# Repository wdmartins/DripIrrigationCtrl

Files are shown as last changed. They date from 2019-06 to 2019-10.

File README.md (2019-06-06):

# DripIrrigationCtrl

Smart Control for Drip Irrigation

This project is aimed to control vegetable garden drip irrigation by setting start dripping time, duration, frequency, rain delay, etc. It also reports water flow measurements.

## Features

* MQTT enabled. Setup and control drip irrigation settings by using MQTT commands.

* LCD Display. Display time and system status on a 16x2 Liquid Crystal Display

* Push Button. Restart system, restart Wi-Fi settings, manual start/stop dripping, and set rain delay using a single push button.

* LED indication. Indicates initialization, normal status, and dripping by flashing LED.

* Peristent Setting Storage. Dripping settings are persistently stored in EEPROM

* OTA. Over the air update is enabled by default.

## Operation

* First time operation. Power the system and connect to the AP (esp8266/esp8266) and navigate to the ip address showed in the display. Setup your WiFi SSID and password so the system can connect to your network.

* Upon restart the system initializes by connecting to the Wi-Fi, setup a connection to the MQTT broker and schedule next dripping period (or start dripping) based on default dripping settings.

* Push Button Operation:

  * Short Push (less than 3 seconds) will start/stop dripping
  * Medium push (less than 8 seconds) will set a 24 hours rain delay.
  * Long Push (more than 8 seconds) will restart the system
  * Power up while pushing button will reset Wi-Fi settings and start the system in AP mode.

* MQTT Commands:

  By default the system subscribes to MQTT topic /home-assistant/drip/request. The payload includes the command (first byte), and the data (subsequent bytes)
  * Dripping Settings Payload: cHH:MM:SSMMHH where HH:MM:SS (24 hours format) is start time, MM duration (in minutes), and HH period (in hours)
  * Rain Delay Payload: rHH where HH is the rain delay in hours
  * Start Dripping Payload: sMM where MM is the dripping time in minutes
  * Stop Dripping Paylod:  t
  * Reset Payload: x
  
  The system will also report using the following MQTT command:

  * /home-assistant/drip/flow the payload will have the metered water flow after each dripping cycle. Payload: xxx where xxx is the total liters.
  * /home-assistant/drip/started drip has started. No payload.
  * /home-assistant/drip/stopped drip has stopped. No payload.

## Schemmatic
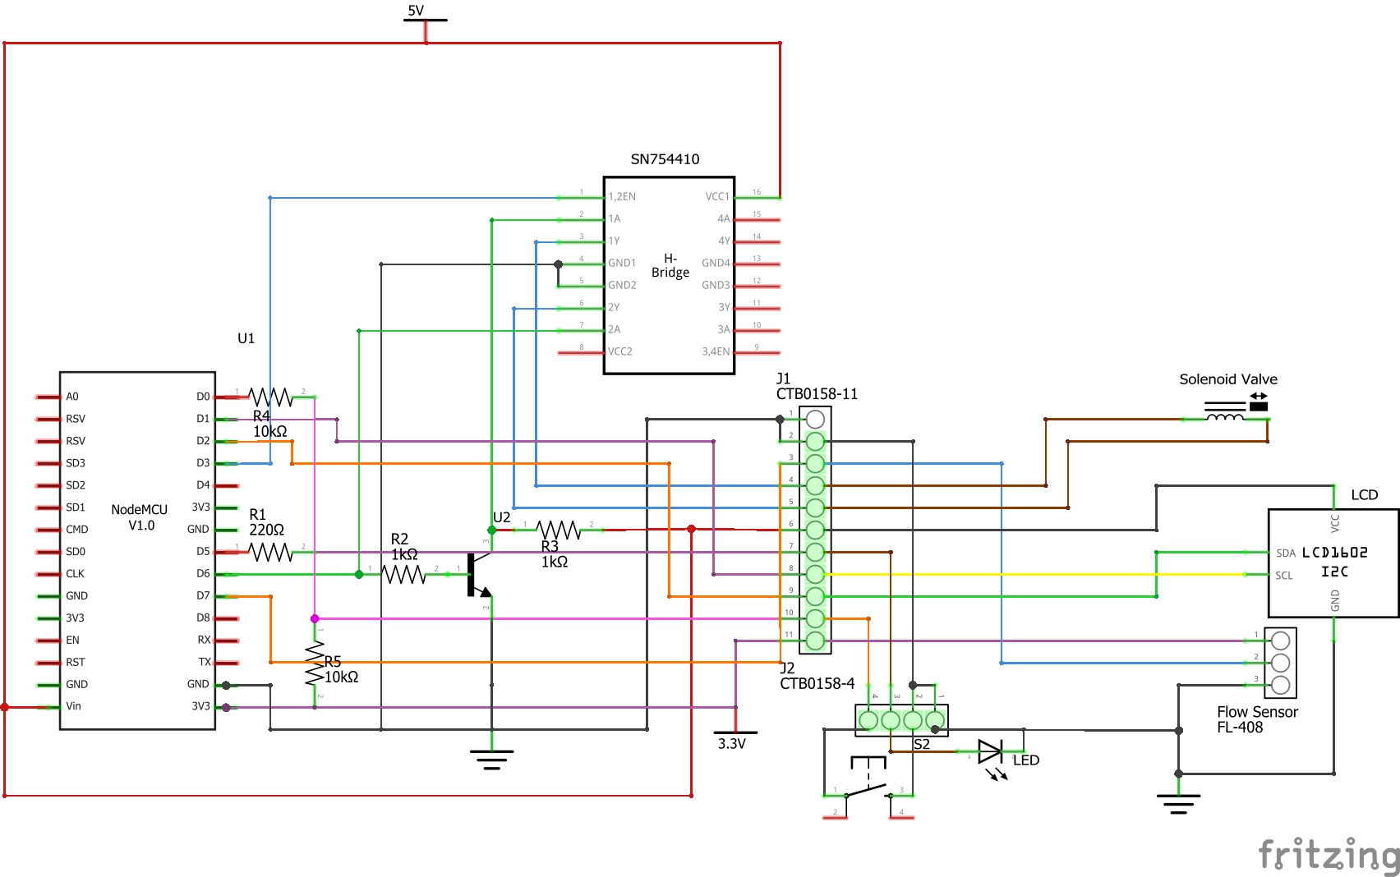
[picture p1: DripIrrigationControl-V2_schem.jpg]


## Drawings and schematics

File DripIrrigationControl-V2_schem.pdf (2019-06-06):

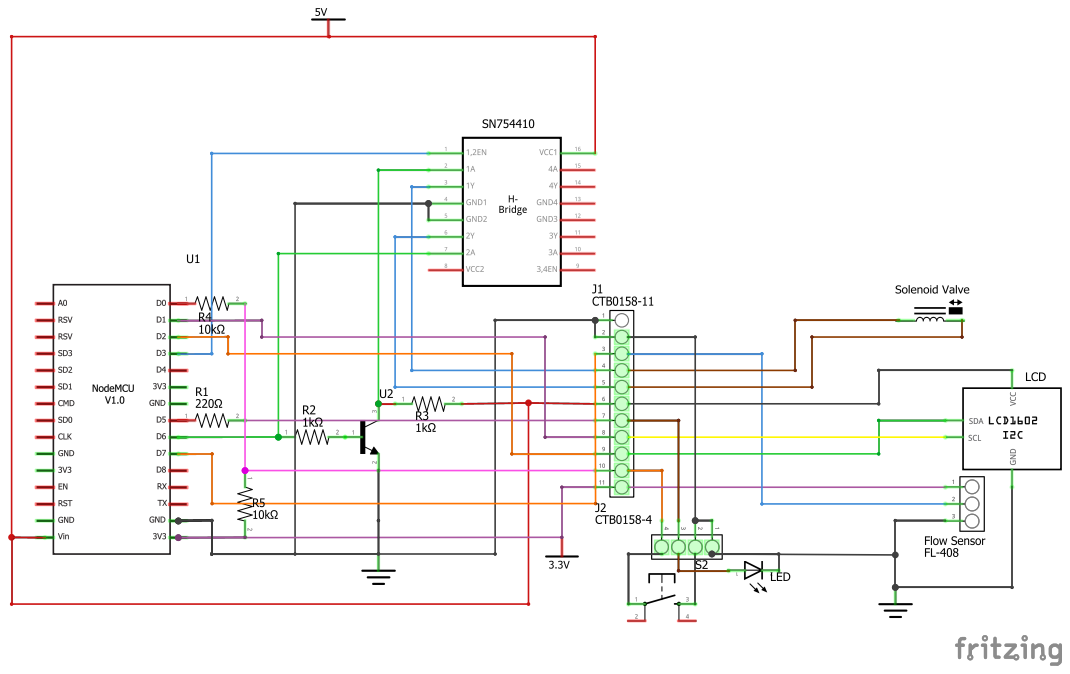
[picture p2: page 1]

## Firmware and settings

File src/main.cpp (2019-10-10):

#include <Arduino.h>
#include <EEPROM.h>
#include <WiFiManager.h>
#include <ArduinoOTA.h>
#include <PubSubClient.h>
#include <TimeUtils.h>
#include <StatusLED.h>
#include <Valves.h>
#include <FlowMeter.h>
#include <time.h>
#include <LongTicker.h>
#include <PushButton.h>
#include <LiquidCrystal_I2C.h>
#include "secret.h"

/*------------------------------------------------------------------------------------*/
/* Constant Definitions                                                               */
/*------------------------------------------------------------------------------------*/
// Access point to configure Wi-Fi
const char* ACCESS_POINT_NAME = "ESP8266";
const char* ACCESS_POINT_PASS = "esp8266";

// Status LED redefinitions
const StatusLED::Status IRRIGATING = StatusLED::Status::custom_1;
const StatusLED::Status ANY_ERROR = StatusLED::Status::custom_2;

// MQTT Constants
const char * MQTT_CLIENT_PREFIX = "DripCtrl-";
const char * MQTT_IN_TOPIC = "/home-assistant/drip/request";

// MQTT Commands
const char MQTT_CMD_CONFIG_DRIP = 'c';   // Configure dripping parameters
const char MQTT_CMD_START_DRIP = 's';    // Start manual dripping
const char MQTT_CMD_STOP_DRIP = 't';     // Stop manual dripping
const char MQTT_CMD_RAIN_DELAY = 'r';    // Set rain delay
const char MQTT_CMD_RESET = 'x';         // Restart system
const char MQTT_CMD_RESET_METER = 'a';   //TODO: restart the flow meter

// MQTT Events
const char * MQTT_REPORT_FLOW = "/home-assistant/drip/flow";
const char * MQTT_DRIP_STARTED = "/home-assistant/drip/started";
const char * MQTT_DRIP_STOPPED = "/home-assistant/drip/stopped";
const char * MQTT_DRIP_SCHEDULE = "/home-assistant/drip/schedule";
const char * MQTT_DRIP_RAIN_DELAY_ENDED = "/home-assistant/drip/raindelayended";
const char * MQTT_DRIP_RAIN_DELAY_SET = "/home-assistant/drip/raindelayset";

// Default Drip Values
const char *START_IRRIGATION_TIME = "07:00:00"; // HH:MM:SS
const uint8_t IRRIGATION_PERIOD_HOURS = 12;         // Minimum 12 hours
const uint8_t IRRIGATION_LONG_MINUTES = 45;         // Maximum 120 minutes
const uint8_t RAIN_DELAY_HOURS = 24;                // Minimum 24 hours

// Other Constants
const uint8_t LCD_DISPLAY_INTERVAL_SECONDS = 60;    // Update the LCD display
const uint8_t WIFI_CONFIG_WAIT_TIME_MINUTES = 5;    // Time waits for WiFi config before resetting

/*------------------------------------------------------------------------------------*/
/* GPIO Definitions                                                                   */
/*------------------------------------------------------------------------------------*/
const uint8_t GPIO_VALVE_ENABLE = 0;       // ESP8266 NodeMCU D3 (OUTPUT)
const uint8_t GPIO_UNUSED_01 = 2;          // ESP8266 NodeMUC D4 (UART)
const uint8_t GPIO_UNUSED_02 = 2;          // ESP8266 NodeMUC D4 (Boot mode. Do not user for INPUT)
const uint8_t GPIO_UNUSED_03 = 3;          // ESP8266 NodeMCU D9 (UART)
const uint8_t GPIO_DISPLAY_SDA = 4;        // ESP8266 NodeMCU D2 (SDA) 
const uint8_t GPIO_DISPLAY_SCL = 5;        // ESP8266 NodeMCU D1 (SCL)
const uint8_t GPIO_UNUSED_06 = 6;          // ESP8266 NodeMCU -+ F M
const uint8_t GPIO_UNUSED_07 = 7;          // ESP8266 NodeMCU  + L E
const uint8_t GPIO_UNUSED_08 = 8;          // ESP8266 NodeMCU  + A M
const uint8_t GPIO_UNUSED_09 = 9;          // ESP8266 NodeMCU  + S O
const uint8_t GPIO_UNUSED_10 = 10;         // ESP8266 NodeMCU  + H R
const uint8_t GPIO_UNUSED_11 = 11;         // ESP8266 NodeMCU -+   Y
const uint8_t GPIO_VALVE_SIGNAL = 12;      // ESP8266 NodeMCU D6 (OUTPUT)
const uint8_t GPIO_FLOW_METER_SIGNAL = 13; // ESP8266 NodeMUC D7 (INPUT
const uint8_t GPIO_STATUS_LED = 14;        // ESP8266 NodeMCU D5 (OUTPUT)
const uint8_t GPIO_UNUSED_15 = 15;         // ESP8266 NodeMCU D8 (Boot from SD Card)
const uint8_t GPIO_PUSH_BUTTON = 16;       // ESP8266 NodeMCU D0 (INPUT)
/*------------------------------------------------------------------------------------*/
/* Helper Classes                                                                     */
/*------------------------------------------------------------------------------------*/
class DripParams {
  public:
    DripParams(const char *startDripTime, uint8_t dripPeriodHours, uint8_t dripTimeMinutes):
    _period(dripPeriodHours),
    _duration(dripTimeMinutes) {
      strcpy(_startTime, startDripTime);
      strptime(startDripTime, "%T", &_start);
      _rainDelayHours = 0;
      _rainDelayResumeTime = TimeUtils::getCurrentTimeRaw() - 1; // No rain delay 
    }
    ~DripParams() {};

    struct tm getStartTime(void) {
      return _start;
    };

    time_t getTodayStartTime(void) {
      struct tm *currentTime = TimeUtils::getCurrentTime();
      currentTime->tm_hour = _start.tm_hour; 
      currentTime->tm_min = _start.tm_min; 
      currentTime->tm_sec = _start.tm_sec;
      return mktime(currentTime); 
    }

    uint32_t getDripPeriodSeconds(void) {
        return _period * 3600;
    }

    uint16_t getDripTimeSeconds(void) {
      return _duration * 60;
    }

    uint8_t getDripTimeMinutes(void) {
      return _duration;
    }

    uint8_t getDripPeriodHours(void) {
      return _period;
    }
    
    void setStartDripTime(char *startTime) {
        //Start time should be in the format HH:MM:SS
        strcpy(_startTime, startTime);
        strptime(startTime, "%T", &_start);
    }

    void setDripPeriodHours(uint8_t hours) {
      _period = hours;
    }

    void setDripTimeMinutes(uint8_t minutes) {
      _duration = minutes;
    }

    void setRainDelay(uint8_t hours) {
      _rainDelayHours = hours;
      _rainDelayResumeTime = TimeUtils::getCurrentTimeRaw() + hours * 3600; 
    }

    void resetRainDelay() {
      _rainDelayHours = 0;
      _rainDelayResumeTime = TimeUtils::getCurrentTimeRaw() - 1; // No rain delay 
    }

    bool isRainDelaySet() {
      return _rainDelayHours > 0;  
    }

    time_t getRainDelayResumeTime(void) {
      return _rainDelayResumeTime;
    }

    const char * toString() {
      sprintf(_auxBuffer, "Start Time: %s, Duration: %d minutes, period: %d hours, Rain Delay: %d hours", 
        _startTime, _duration, _period, _rainDelayHours);
      return _auxBuffer;
    }

    void saveToEEPROM() {
      Serial.println("[DRIPCTR]: Saving Scheduling Data to EEPROM");
      // EPROM Struct
      // Byte 0: Valid Data 00, Invalid Data FF
      // Byte 1: Start time hour 0-23
      // Byte 2: Start time minute 0-59
      // Byte 3: Start time second 0-59
      // Byte 4: Drip Period 0,6,12,24
      // Byte 5: Dripping Duration Minutes 0-255
      // Rain delay will not be save and will not survive reboot.
      uint8_t addr = 0;
      EEPROM.write(addr, 0x00); addr++;
      EEPROM.write(addr, _start.tm_hour); addr++;
      EEPROM.write(addr, _start.tm_min); addr++;
      EEPROM.write(addr, _start.tm_sec); addr++;
      EEPROM.write(addr, _period); addr++;
      EEPROM.write(addr, _duration); addr++;
      EEPROM.commit();
      Serial.println("[DRIPCTR]: Finished Saving Scheduling Data to EEPROM");
    }
    void restoreFromEEPROM() {
      Serial.println("[DRIPCTR]: Restoring Scheduling Data from EEPROM");
      uint8_t addr = 0;
      byte value = EEPROM.read(addr); addr++;
      if (value == 0x00) {
        // Valid data on EEPROM
        uint8_t hour = EEPROM.read(addr); addr++;
        uint8_t min = EEPROM.read(addr); addr++;
        uint8_t sec = EEPROM.read(addr); addr++;
        uint8_t period = EEPROM.read(addr); addr++;
        uint8_t duration = EEPROM.read(addr);
        // Validate values
        if (hour >= 0 && hour <= 23 && min >= 0 && min <= 59 && sec >= 0 && sec <= 59) {
          // Valid start time
          sprintf(_startTime, "%02u:%02u:%02u", hour, min, sec);
          _start.tm_hour = hour;
          _start.tm_min = min;
          _start.tm_sec = sec;

          if (period % 6 == 0 && period <= 24) {
            // Valid period time
            _period = period; 
            _duration = duration;
            Serial.println("[DRIPCTR]: Scheduling data restored from EEPROM");
            Serial.printf("[DRIPCTR]: Schedule: %s\n", toString());
          } else {
            Serial.printf("[DRIPCTR]: EEPROM contains invalid period %02d\n", period);
          }
        } else {
          Serial.printf("[DRIPCTR]: EEPROM contains invalid start time %02d:%02d:%02d\n", hour, min, sec);
        }
      } else {
        Serial.println("[DRIPCTR]: Scheduling Data on EEPROM is not valid. May be has never been saved");
      }
    }
  private:
    char _auxBuffer[200];
    char _startTime[100];
    struct tm _start;
    uint8_t _period;
    uint8_t _duration;
    uint8_t _rainDelayHours;
    time_t _rainDelayResumeTime;
};


/*------------------------------------------------------------------------------------*/
/* Global Variables                                                                   */
/*------------------------------------------------------------------------------------*/
// WiFi Manager
WiFiManager wifiManager;

// Intervals
LongTicker dripTicker("DRIPTICK");   // Dripping Scheduling
LongTicker wiFiConfig("WIFICONFIG"); // Wait for WiFi Configuration before resetting system
Ticker lcdDisplayUpdate; // Update LCD text

// MQTT
WiFiClient espClient;
PubSubClient mqttClient(espClient);

// Drip Valve and Flow Meter
SolenoidValve solenoidValve(GPIO_VALVE_ENABLE, GPIO_VALVE_SIGNAL);
FlowMeter flowMeter(GPIO_FLOW_METER_SIGNAL);

// Status LED
StatusLED statusLed(GPIO_STATUS_LED); 

// Default Drip Parameters.
DripParams dripParams(START_IRRIGATION_TIME, IRRIGATION_PERIOD_HOURS, IRRIGATION_LONG_MINUTES);

// Push Button
PushButton pushButton(GPIO_PUSH_BUTTON, 2, 8);

// Liquid Crystal Display
LiquidCrystal_I2C lcd(0x27,16,2);

// First Line LCD
char lcdLine[17] = "\0";

// Next Drip, dripping remaining, rain delay ramaining
time_t toDisplay;

/*------------------------------------------------------------------------------------*/
/* WiFi Manager Global Functions                                                      */
/*------------------------------------------------------------------------------------*/
void reset() {
  ESP.reset();
}
// WiFiManager Configuration CallBack
void configModeCallback (WiFiManager *myWiFiManager) {
  lcd.clear();
  lcd.setCursor(0,0);
  lcd.print("Config WiFi");
  lcd.setCursor(0,1);
  lcd.print(WiFi.softAPIP());
  statusLed.setStatus(ANY_ERROR);
  Serial.println("[WIFI]: Entered config mode");
  Serial.print("[WIFI]:"); Serial.println(WiFi.softAPIP());
  Serial.printf("[WIFI]: %s", (myWiFiManager->getConfigPortalSSID()).c_str());
  // Sometimes the WiFiManager incorrectly enters config mode.
  // Wait a couple of minutes and then reset ESP and try connected to WiFi again
  wiFiConfig.once(WIFI_CONFIG_WAIT_TIME_MINUTES, reset);
}

/*------------------------------------------------------------------------------------*/
/* Other Global Functions                                                             */
/*------------------------------------------------------------------------------------*/
void scheduleDrip(bool manualStop);
void scheduleDrip(void);

void reportFlow() {
  char payload[20];
  sprintf(payload, "%d", flowMeter.getCountedLiters(true));
  Serial.printf("[DRIPCTRL]: Reporting flow. Liters: %s\n", payload);
  mqttClient.publish(MQTT_REPORT_FLOW, payload);
}

void updateLcd(bool noTimeDisplay) {
  char aux[50];
  time_t now = TimeUtils::getCurrentTimeRaw();
  Serial.printf("[DEBUG]: toDisplay: %ld\n", toDisplay);
  uint32_t remaining = toDisplay - now;
  uint16_t minutes = remaining / 60;
  uint8_t hours = 0;
  Serial.printf("[DEBUG]: remaining: %d\n", remaining);
  if (minutes > 59) {
     hours = minutes / 60;
     minutes = minutes % 60;
  }
  Serial.printf("[DEBUG]: hours: %02d, minutes: %02d\n", hours, minutes);
  sprintf(aux, "%s %02d:%02d", lcdLine, hours, minutes);
  lcd.clear();
  lcd.setCursor(0,0);
  lcd.print(noTimeDisplay ? lcdLine : aux);
  lcd.setCursor(0,1);
  lcd.print(TimeUtils::getTimeStr(now).c_str());
  mqttClient.publish(MQTT_DRIP_SCHEDULE, noTimeDisplay ? lcdLine : aux);
}

void stopScheduledDrip(void) {
  solenoidValve.closeValve();
  mqttClient.publish(MQTT_DRIP_STOPPED, "");
  reportFlow();
  statusLed.setStatus(StatusLED::Status::stable);
  scheduleDrip();
}

void startScheduledDrip(void) {
  solenoidValve.openValve();
  mqttClient.publish(MQTT_DRIP_STARTED, "");
  statusLed.setStatus(IRRIGATING);
  sprintf(lcdLine,"Dripping");
  // Current Time
  time_t nowRaw = TimeUtils::getCurrentTimeRaw();
  // Dripping duration
  uint16_t duration = dripParams.getDripTimeSeconds();
  toDisplay = nowRaw + duration;
  dripTicker.once(duration / 60, stopScheduledDrip);
  updateLcd(false);
}

void scheduleDrip() {
  scheduleDrip(false);
}

void scheduleDrip(bool manualStop) {
  // Scheduler: 
  //           Depending on the parameters, the result of the scheduling could be:
  //           1. Start dripping. Schedule to stop
  //              The current time is in between dripping scheduled periods
  //           2. Schedule to start dripping
  //              The current time is outside dripping scheduled periods but there is a dripping schedule for today
  //           3. Schedule to reschedule
  //              The current time is later than any schedule period for today, or there is a rain delay

  Serial.printf("[DRIPCTRL] Scheduling: %s\n", dripParams.toString());
  
  // Current Time
  time_t nowRaw = TimeUtils::getCurrentTimeRaw();
  // First schedule dripping for today
  time_t dripStart = dripParams.getTodayStartTime();
  // Dripping duration
  uint16_t duration = dripParams.getDripTimeSeconds();
  // Dripping time in seconds. If set to greatet than 0, then the result was #1. See above.
  uint16_t dripTimeSeconds = 0;
  // Time to next dripping in seconds. If set to greater than 0, then the result was #2. See above.
  uint32_t timeToNextDripSeconds = 0;
  // Time to next scheduling in minutes. If set to greater that 0, the the result was #3. See above.
  uint16_t rescheduleTimeMinutes = 0;
  // Second dripping of the day
  time_t secondTime = dripStart + dripParams.getDripPeriodSeconds();
  // Rain delay: resume time
  time_t rainDelayResumeTime = dripParams.getRainDelayResumeTime();
  
  // Is there a rain delay in effect?
  if (nowRaw < rainDelayResumeTime - 60) {
    // Reschedule at rainDelayResumeTime
    rescheduleTimeMinutes = (rainDelayResumeTime - nowRaw) / 60;
    toDisplay = rainDelayResumeTime;
    Serial.printf("[DRIPCTRL]: Within rain delay. Reschedule in %d minutes\n", rescheduleTimeMinutes);
  } else if (nowRaw < dripStart) {
    // Too early to start dripping today
    timeToNextDripSeconds = dripStart - nowRaw;
    Serial.println("[DRIPCTRL]: Too early for first dripping");
    toDisplay = dripStart;
  } else if (nowRaw >= dripStart && nowRaw < (dripStart + duration) && !manualStop) {
    // Within first dripping of the day
    dripTimeSeconds = dripStart + duration - nowRaw + 1;  
    toDisplay = dripStart + duration;
  } else if ( nowRaw >= secondTime && nowRaw < (secondTime + duration) && !manualStop) {
    // Within second dripping of the day
    dripTimeSeconds = secondTime + duration - nowRaw + 1;
    toDisplay = secondTime + duration;
  } else if ( nowRaw < secondTime) {
    // Too late for first dripping. Too early for next
    Serial.println("[DRIPCTRL]: Too late for first, too early for second");
    timeToNextDripSeconds = secondTime - nowRaw + 1;
    toDisplay = secondTime;
  } else {
    // Too late for dripping today
    Serial.println("[DRIPCTRL]: Not more dripping today. Reschedule at midnight");
    rescheduleTimeMinutes = TimeUtils::minutesTillMidnight();
    toDisplay = dripStart + 24 * 3600;
  }
  if (dripTimeSeconds > 0) {
    // #1 Start dripping. Schedule to stop
    dripTimeSeconds = dripTimeSeconds < 60 ? 60 : dripTimeSeconds;
    Serial.printf("[DRIPCTRL]: Start Drip for %d seconds\n", dripTimeSeconds);
    statusLed.setStatus(IRRIGATING);
    solenoidValve.openValve();
    mqttClient.publish(MQTT_DRIP_STARTED, "");
    dripTicker.once((dripTimeSeconds / 60) + 1, stopScheduledDrip);
    sprintf(lcdLine, "Dripping");
  } else if (rescheduleTimeMinutes > 0) {
    // #3 Too late for dripping today, or rain delay. Schedule to re-schedule
    dripTicker.once(rescheduleTimeMinutes + 1, scheduleDrip);
    sprintf(lcdLine, dripParams.isRainDelaySet() ? "Rain Delay" : "Done today");
  } else {
    // #2 Schedule to start dripping
    Serial.printf("[DRIPCTRL]: Not time for dripping. %d seconds to next dripping.\n", timeToNextDripSeconds);
    timeToNextDripSeconds = timeToNextDripSeconds < 60 ? 60 : timeToNextDripSeconds;
    dripTicker.once((timeToNextDripSeconds / 60) + 1, startScheduledDrip);
    sprintf(lcdLine, dripParams.isRainDelaySet() ? "Rain Delay" : "Scheduled");
  }
  updateLcd(false);
  if (!dripParams.isRainDelaySet()) {
    mqttClient.publish(MQTT_DRIP_RAIN_DELAY_ENDED, "");
  }
}

/*------------------------------------------------------------------------------------*/
/* MQTT Global Functions                                                              */
/*------------------------------------------------------------------------------------*/
// MQTT Subscribe Callback
void callback(char* topic, byte* payload, uint8_t length) {
  bool noTimeDisplay = false;
  Serial.printf("[MQTT]: Message arrived [%s]\n", topic);
  Serial.print("[MQTT]: Payload (");
  for (uint8_t i=0; i < length; i++) {
    Serial.print((char)payload[i]);
  }
  Serial.println(")");
  char aux[40];
  uint8_t rainDelay;
  switch((char) payload[0]) {
    case MQTT_CMD_CONFIG_DRIP: // Configutation in the format of HH:MM:SSMMHH where HH:MM:SS is start time, MM duration, and HH period
      sprintf(aux, "%c%c", payload[9], payload[10]);
      dripParams.setDripTimeMinutes(atoi(aux));
      sprintf(aux, "%c%c", payload[11], payload[12]);
      dripParams.setDripPeriodHours(atoi(aux));
      sprintf(aux,"%c%c:%c%c:%c%c", payload[1], payload[2], payload[4], payload[5], payload[7], payload[8]);
      dripParams.setStartDripTime(aux);
      Serial.printf("[DRIPCTRL]: New Drip Configuration: StartTime(%s), Duration(%d minutes), Period(%d hours)\n", 
        aux, dripParams.getDripTimeMinutes(), dripParams.getDripPeriodHours());

      if (!solenoidValve.isValveOpen()) {
          dripTicker.detach();
          scheduleDrip();
      }
      dripParams.saveToEEPROM();
      break;
    case MQTT_CMD_RAIN_DELAY: // Rain delay in the format of HH which is hours to not drip
      sprintf(aux, "%c%c", payload[1], (length <= 2 ? 0 : payload[2]));
      rainDelay = atoi(aux);
      if (rainDelay > 0) {
        dripParams.setRainDelay(atoi(aux));
        Serial.printf("[DRIPCTRL]: Rain delay set for %s hours\n", aux);
        if (!solenoidValve.isValveOpen()) {
            dripTicker.detach();
            scheduleDrip();
        }
        sprintf(lcdLine, "Rain Delay");
      } else {
        Serial.println("[DRIPCTRL]: Cancel rain delay");
        dripTicker.detach();
        dripParams.setRainDelay(0);
        scheduleDrip();
      }
      break;
    case MQTT_CMD_START_DRIP: // Start dripping in the format of MM which is the drip time in minutes
      sprintf(aux, "%c%c", payload[1], payload[2]);
      Serial.printf("[DRIPCTRL]: Start manual dripping for %s minutes\n", aux);
      if (solenoidValve.isValveOpen()) {
        Serial.println("[DRIPCTRL]: Already dripping. Ignore Command");
        return;
      }
      dripTicker.detach();
      solenoidValve.openValve();
      mqttClient.publish(MQTT_DRIP_STARTED, "");
      statusLed.setStatus(IRRIGATING);
      dripTicker.once(atoi(aux), stopScheduledDrip);
      toDisplay = TimeUtils::getCurrentTimeRaw() + atoi(aux) * 60;
      sprintf(lcdLine, "Driping");
      break;
    case MQTT_CMD_STOP_DRIP: // Stop dripping
      Serial.println("[DRIPCTRL]: Stop manual dripping");
      if (!solenoidValve.isValveOpen()) {
        Serial.println("[DRIPCTRL]: Not dripping now. Ignore Command");
        return;
      }
      dripTicker.detach();
      solenoidValve.closeValve();
      mqttClient.publish(MQTT_DRIP_STOPPED, "");
      reportFlow();
      statusLed.setStatus(StatusLED::Status::stable);
      scheduleDrip(true);
      break;
    case MQTT_CMD_RESET: // Reset system
      sprintf(lcdLine, "Reseting");
      updateLcd(true);
      Serial.println("[DRIPCTRL]: Reseting system...");
      delay(5);
      ESP.reset();
      break;
    default: 
      Serial.printf("[MQTT]: Unknown MQTT Command: %c\n", (char) payload[0]);
      break;
  }
  updateLcd(noTimeDisplay);
}

// MQTT Client reconnection
void reconnect() {
  // Loop until we're reconnected
  while (!mqttClient.connected()) {
    Serial.println("[MQTT]: Attempting MQTT connection...");
    // Create a random client ID
    String clientId = MQTT_CLIENT_PREFIX;
    clientId += String(random(0xffff), HEX);
    // Attempt to connect
    if (mqttClient.connect(clientId.c_str(), MQTT_USERNAME, MQTT_PASSWORD)) {
      Serial.println("[MQTT]: Connected");
      // ... and resubscribe
      mqttClient.subscribe(MQTT_IN_TOPIC);
    } else {
      Serial.printf("[MQTT]: Failed, rc= %d, try again in 5 seconds\n", mqttClient.state());
      // Visual Indication
      sprintf(lcdLine, "MQTT Error: %d",mqttClient.state());
      updateLcd(true);
      statusLed.setStatus(ANY_ERROR);
      // Wait 5 seconds before retrying
      delay(5000);
    }
  }
}
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
void loop() {
  // OTA
  ArduinoOTA.handle();
  
  // Flow Meter
  flowMeter.run();

  // MQTT
  if (!mqttClient.connected()) {
    reconnect();
  }
  mqttClient.loop();

  // Push Button
  pushButton.run();

  // Solenoid Valve
  solenoidValve.run();

}

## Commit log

2019-06-01 Migration from Arduino IDE to PlatformIO
2019-06-02 Switch D0 (Flow Meter) and D7 (Push Button)
2019-06-04 Added WiFi Settings Reset on Long Push button
    [main.cpp]
2019-06-05 Fixed display while dripping
    [main.cpp]
2019-06-05 Reset WiFi Credentials with Pushed button at startup
    [main.cpp]
2019-06-05 Replace int by uintx_t. Fixed Rain Delay Display
    [main.cpp]
2019-06-06 Schematics Added
    [DripIrrigationControl-V2.fzz]
2019-06-06 Added Schematic Image
2019-06-16 Added MQTT Drip Schedule Report, and Rail Delay Sync with Home Assistant
2019-10-10 Improved initialization. Reset every 5 minutes when no wifi
    [main.cpp]
